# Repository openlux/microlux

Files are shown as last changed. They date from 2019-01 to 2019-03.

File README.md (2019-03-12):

This project is still in development.

# microlux

microlux is an open source design for an astrophotography autoguiding camera designed around the Aptina AR0130 image sensor.

### Hardware specifications

* AR0130 image sensor in ILCC48 package
  * 1280x960 resolution
  * 1/3-inch (6mm) diagonal size
  * 3.75um pixels
  * 78% peak quantum efficiency

* CY7C68013A microcontroller in QFN56 package
  * High speed USB 2.0 (480Mb/s)
  * Quad buffered 16/8 bit FIFO

* 40mm circular PCB
  * Designed to fit inside T2 / 42mm dust cap
  * 4x mounting holes for M2.5 screws (20mm square spacing)
  * Micro USB connector
  * RJ12 connector for ST4-compatible autoguiding

### PCB fab requirements

* Min. trace width 6mil
* Min. trace/pad spacing 6mil
* Min. drill 0.35mm
* Max. drill 2.7mm
* Min. via diameter 0.6mm
* Copper thickness 1.37mil (1oz/ft<sup>2</sup>)
* PCB thickness 0.8-1.6mm

### PCB photo

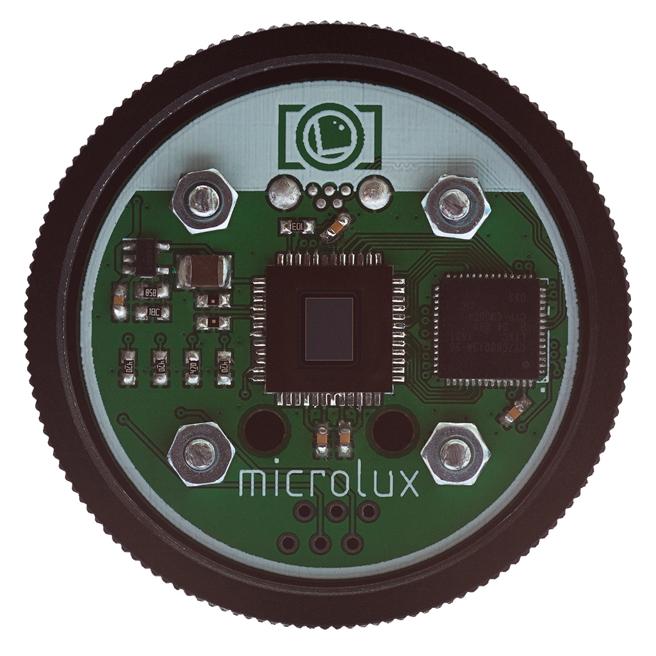
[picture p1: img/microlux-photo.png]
Microlux photo


### PCB render

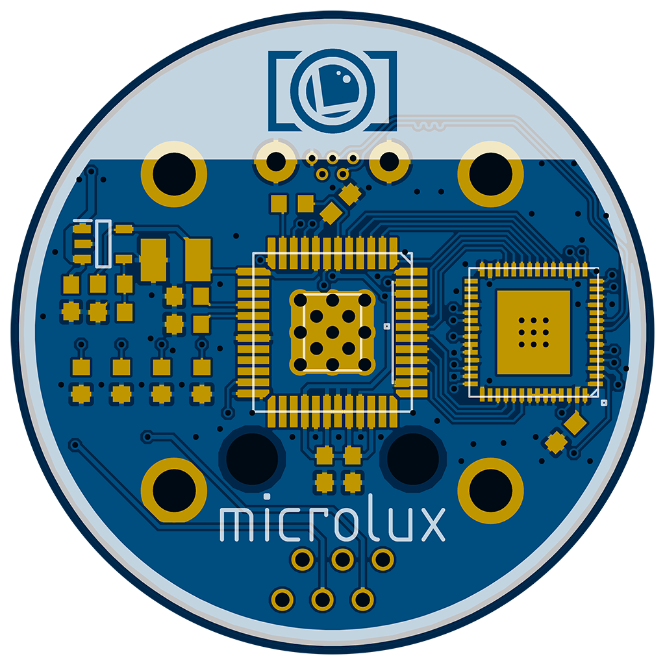
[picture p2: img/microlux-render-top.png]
Microlux PCB render


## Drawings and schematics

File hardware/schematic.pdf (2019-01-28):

A

A

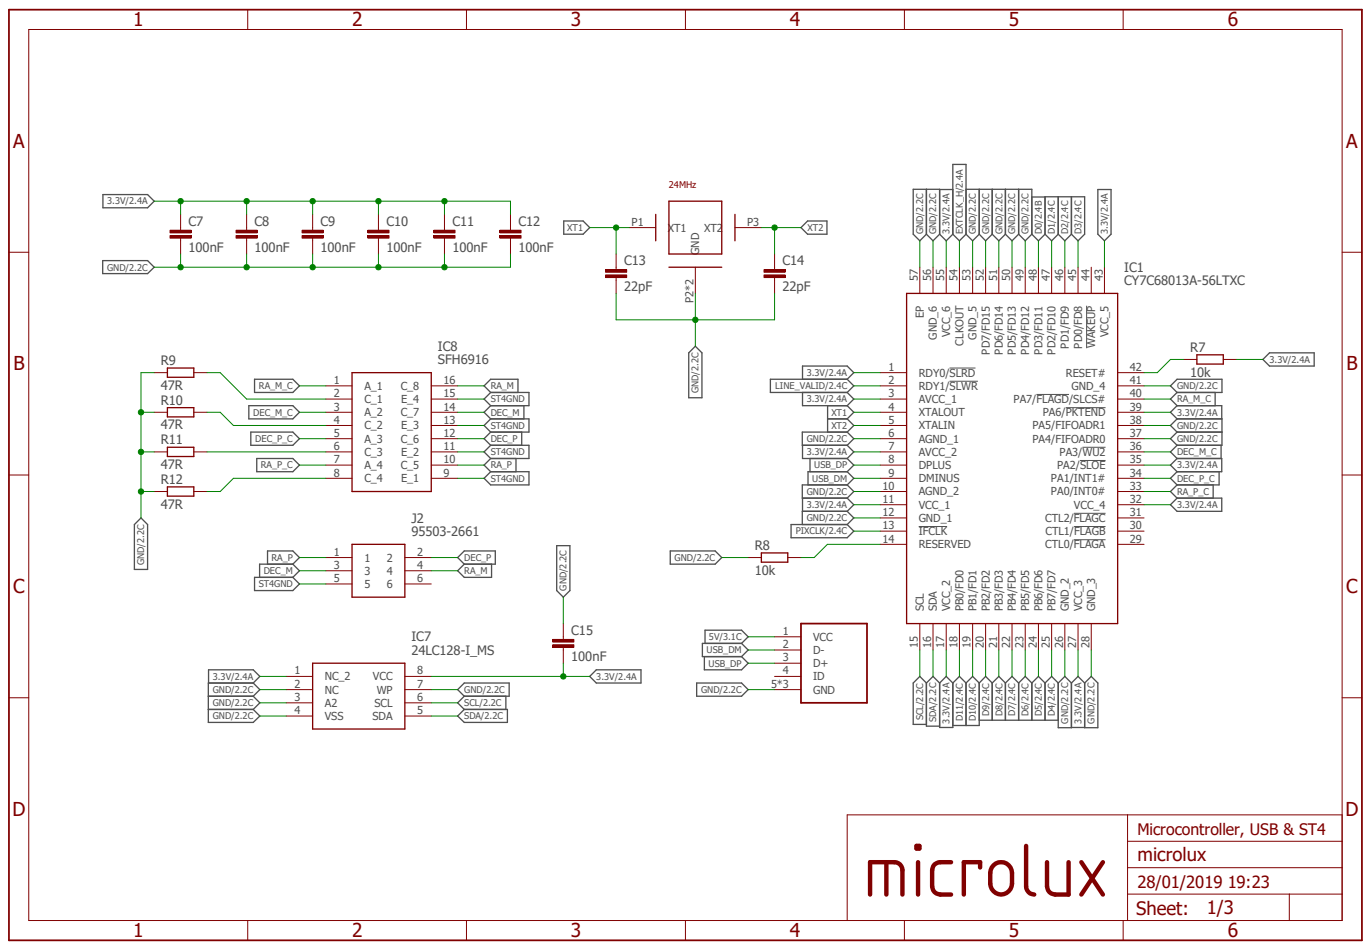
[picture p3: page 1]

## SN74LVC1T45DBVT

IC6

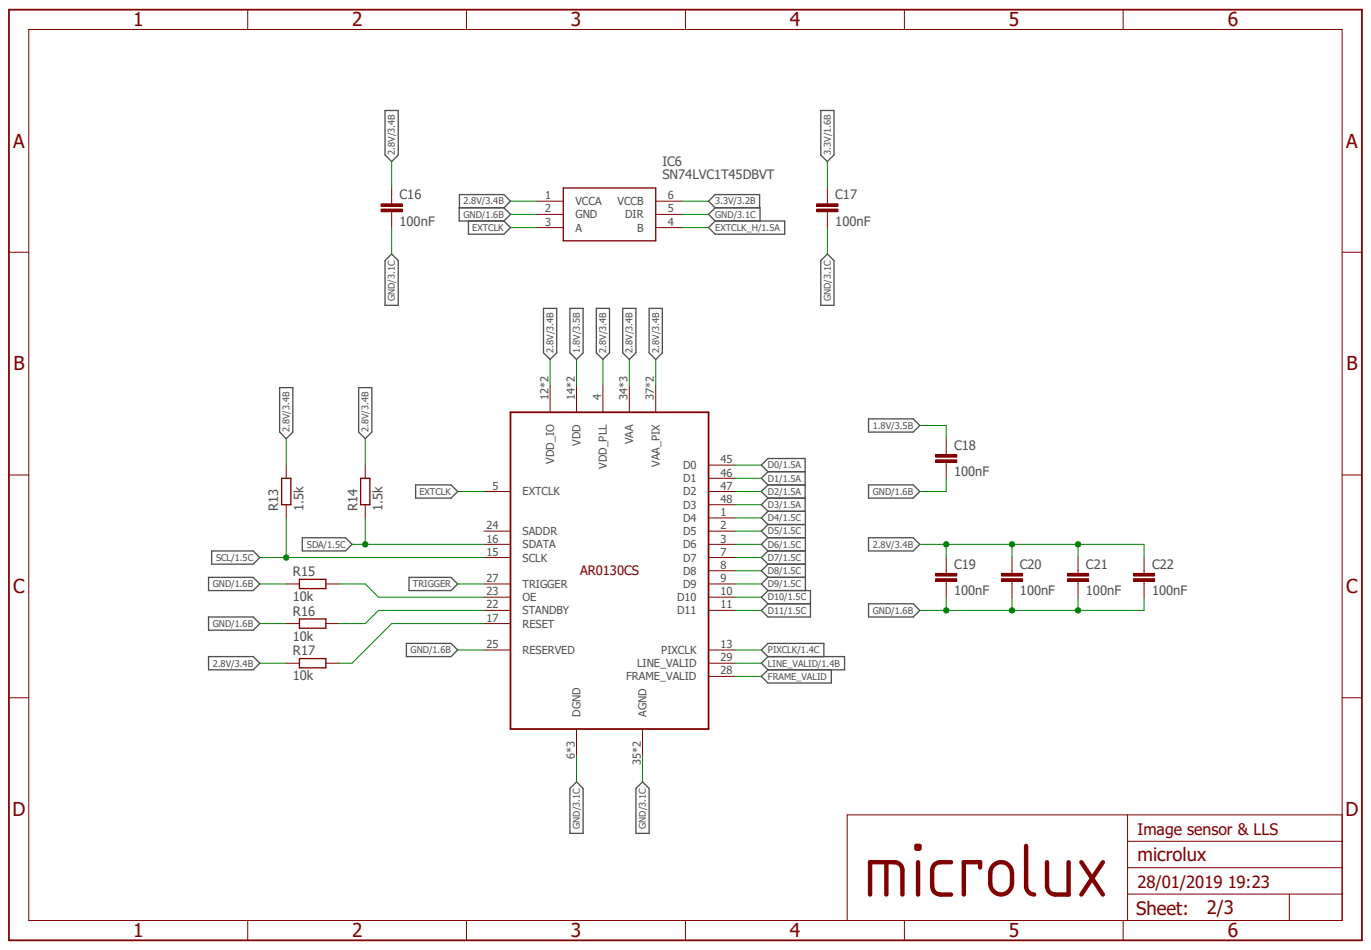
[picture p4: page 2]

A

A

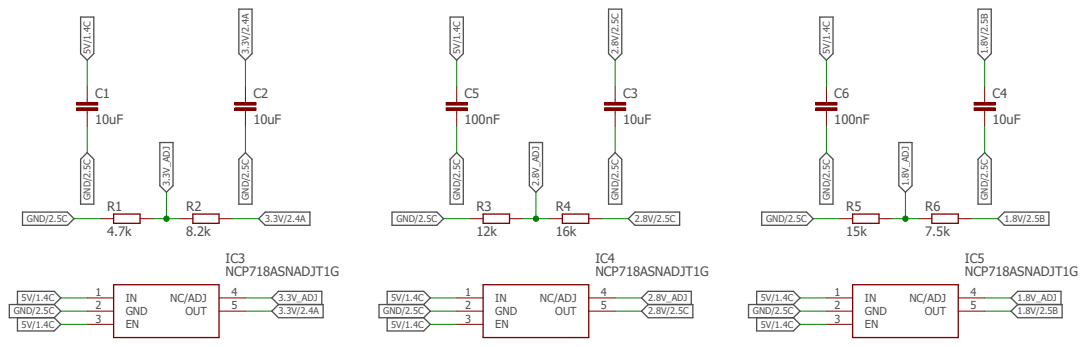
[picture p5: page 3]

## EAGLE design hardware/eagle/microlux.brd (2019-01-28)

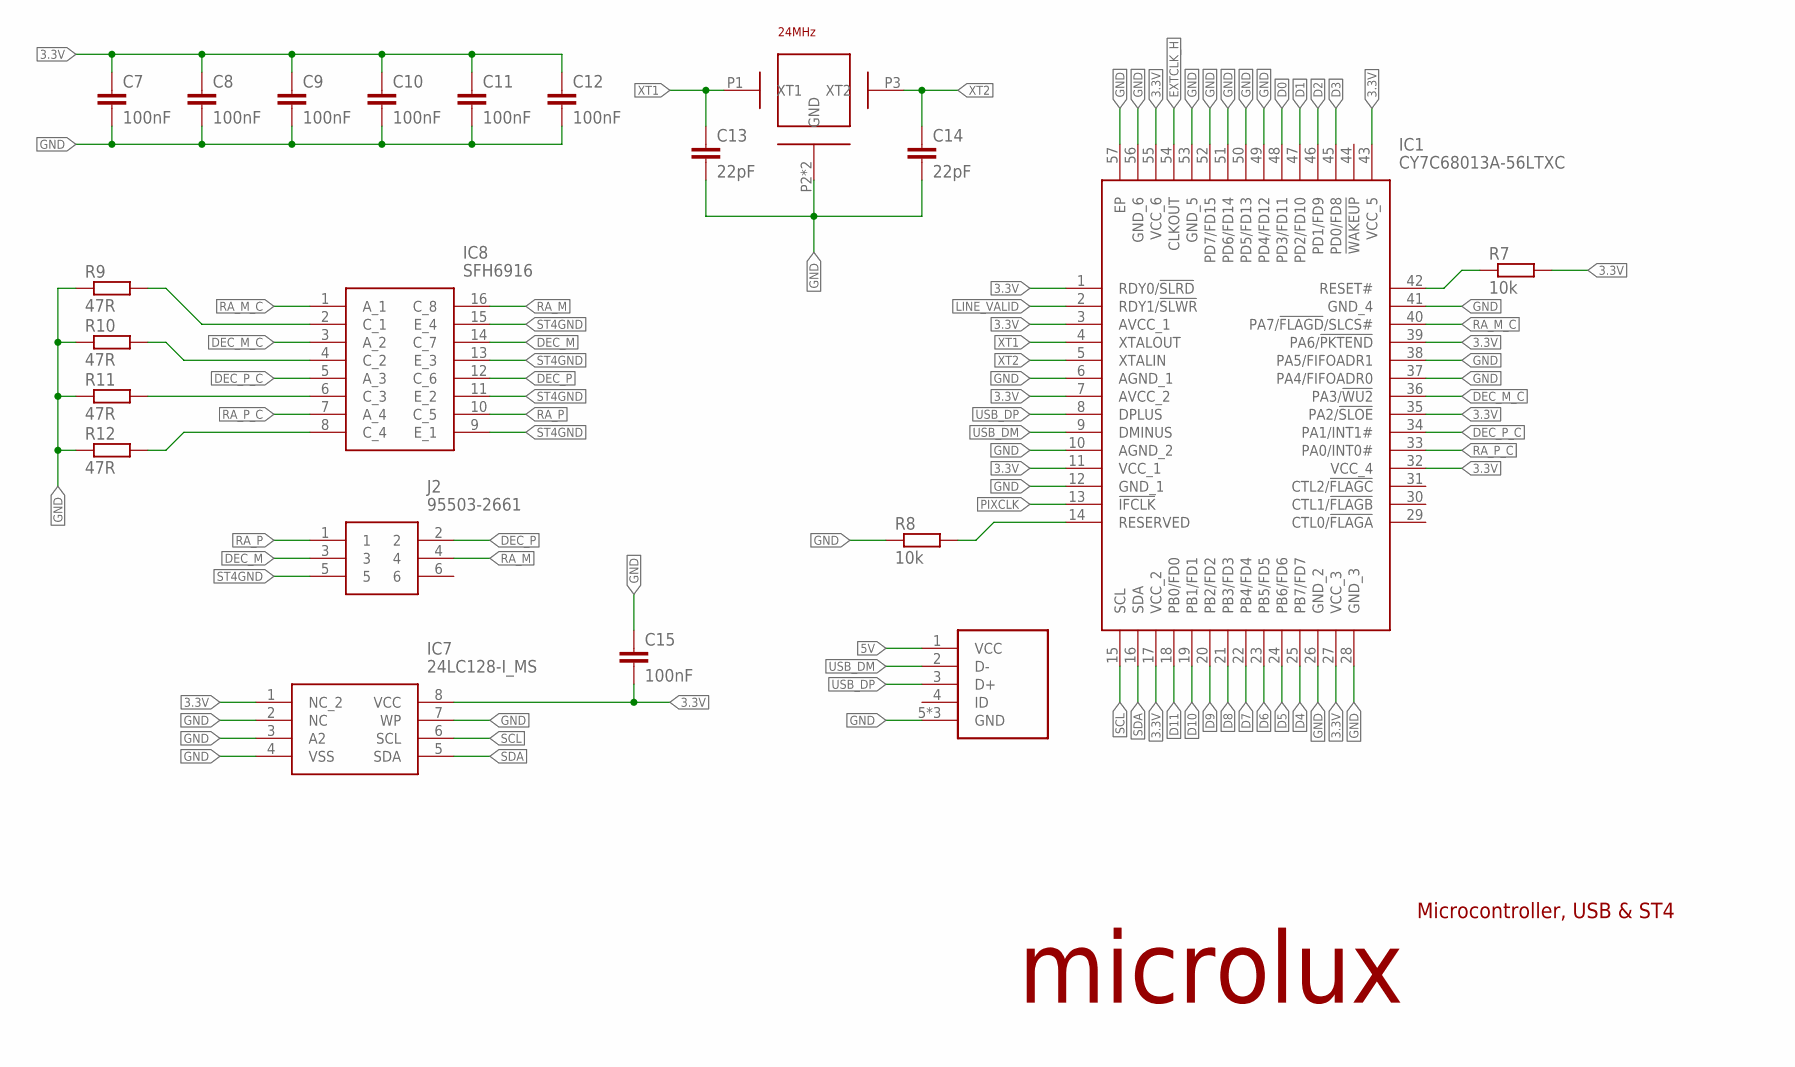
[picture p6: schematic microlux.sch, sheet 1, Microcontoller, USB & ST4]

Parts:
C7, C8, C9, C10, C11, C12, C15: 100nF; C0603
C13, C14: 22pF; C0603
IC1: CY7C68013A-56LTXC; QFN50P800X800X100-57N
IC7: 24LC128-I_MS; SOP65P490X110-8N
IC8: SFH6916; SOIC127P686X216-16N
J1: 614105150621; VMUSB
J2: 95503-2661; 955032661
R7, R8: 10k; R0603
R9, R10, R11, R12: 47R; R0603
X1: 24MHz; 3.2X2.5

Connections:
3.3V: C7.1, C8.1, C9.1, C10.1, C11.1, C12.1, C15.2, IC1.1 (RDY0/!SLRD), IC1.3 (AVCC_1), IC1.7 (AVCC_2), IC1.11 (VCC_1), IC1.17 (VCC_2), IC1.27 (VCC_3), IC1.32 (VCC_4), IC1.35 (PA2/!SLOE), IC1.39 (PA6/!PKTEND), IC1.43 (VCC_5), IC1.55 (VCC_6), IC7.1 (NC_2), IC7.8 (VCC), R7.2; also elsewhere on the board
5V: J1.1 (VCC); also elsewhere on the board
D0: IC1.48 (PD3/FD11); also elsewhere on the board
D1: IC1.47 (PD2/FD10); also elsewhere on the board
D2: IC1.46 (PD1/FD9); also elsewhere on the board
D3: IC1.45 (PD0/FD8); also elsewhere on the board
D4: IC1.25 (PB7/FD7); also elsewhere on the board
D5: IC1.24 (PB6/FD6); also elsewhere on the board
D6: IC1.23 (PB5/FD5); also elsewhere on the board
D7: IC1.22 (PB4/FD4); also elsewhere on the board
D8: IC1.21 (PB3/FD3); also elsewhere on the board
D9: IC1.20 (PB2/FD2); also elsewhere on the board
D10: IC1.19 (PB1/FD1); also elsewhere on the board
D11: IC1.18 (PB0/FD0); also elsewhere on the board
DEC_M: IC8.14 (C_7), J2.3
DEC_M_C: IC1.36 (PA3/!WU2), IC8.3 (A_2)
DEC_P: IC8.12 (C_6), J2.2
DEC_P_C: IC1.34 (PA1/INT1#), IC8.5 (A_3)
EXTCLK_H: IC1.54 (CLKOUT); also elsewhere on the board
GND: C7.2, C8.2, C9.2, C10.2, C11.2, C12.2, C13.2, C14.2, C15.1, IC1.6 (AGND_1), IC1.10 (AGND_2), IC1.12 (GND_1), IC1.26 (GND_2), IC1.28 (GND_3), IC1.37 (PA4/FIFOADR0), IC1.38 (PA5/FIFOADR1), IC1.41 (GND_4), IC1.49 (PD4/FD12), IC1.50 (PD5/FD13), IC1.51 (PD6/FD14), IC1.52 (PD7/FD15), IC1.53 (GND_5), IC1.56 (GND_6), IC1.57 (EP), IC7.2 (NC), IC7.3 (A2), IC7.4 (VSS), IC7.7 (WP), J1.5 (GND), J1.M1 (GND), J1.M2 (GND), R8.1, R9.1, R10.1, R11.1, R12.1, X1.P2 (GND), X1.P4 (GND); also elsewhere on the board
LINE_VALID: IC1.2 (RDY1/!SLWR); also elsewhere on the board
unnamed: IC1.14 (RESERVED), R8.2
unnamed: IC8.2 (C_1), R9.2
unnamed: IC1.42 (RESET#), R7.1
unnamed: IC8.4 (C_2), R10.2
unnamed: IC8.6 (C_3), R11.2
unnamed: IC8.8 (C_4), R12.2
PIXCLK: IC1.13 (!IFCLK); also elsewhere on the board
RA_M: IC8.16 (C_8), J2.4
RA_M_C: IC1.40 (PA7/!FLAGD!/SLCS#), IC8.1 (A_1)
RA_P: IC8.10 (C_5), J2.1
RA_P_C: IC1.33 (PA0/INT0#), IC8.7 (A_4)
SCL: IC1.15 (SCL), IC7.6 (SCL); also elsewhere on the board
SDA: IC1.16 (SDA), IC7.5 (SDA); also elsewhere on the board
ST4GND: IC8.9 (E_1), IC8.11 (E_2), IC8.13 (E_3), IC8.15 (E_4), J2.5
USB_DM: IC1.9 (DMINUS), J1.2 (D-)
USB_DP: IC1.8 (DPLUS), J1.3 (D+)
XT1: C13.1, IC1.4 (XTALOUT), X1.P1 (XT1)
XT2: C14.1, IC1.5 (XTALIN), X1.P3 (XT2)

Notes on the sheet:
microlux
Microcontroller, USB & ST4

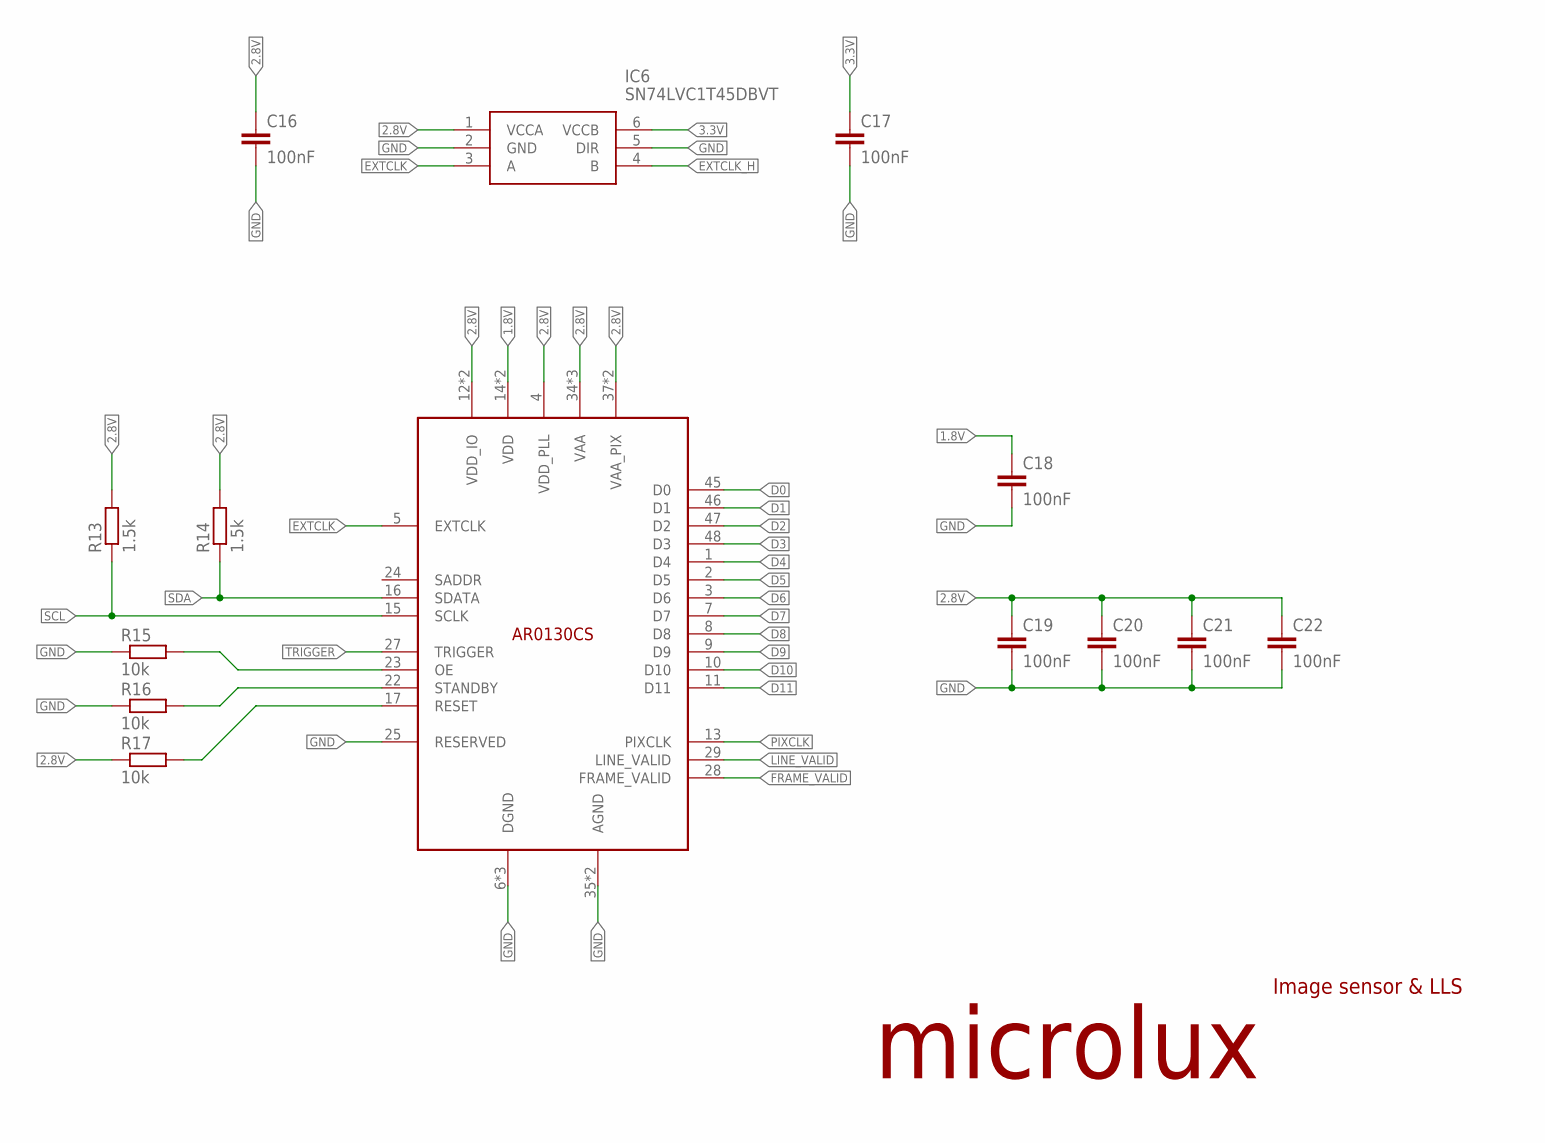
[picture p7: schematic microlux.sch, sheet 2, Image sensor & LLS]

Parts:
C16, C17, C18, C19, C20, C21, C22: 100nF; C0603
IC2: AR0130CS-ILCC48; ILCC48
IC6: SN74LVC1T45DBVT; SOT95P280X145-6N
R13, R14: 1.5k; R0603
R15, R16, R17: 10k; R0603

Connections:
1.8V: C18.1, IC2.14 (VDD), IC2.19 (VDD); also elsewhere on the board
2.8V: C16.1, C19.1, C20.1, C21.1, C22.1, IC2.4 (VDD_PLL), IC2.12 (VDD_IO), IC2.18 (VDD_IO), IC2.34 (VAA), IC2.36 (VAA), IC2.37 (VAA_PIX), IC2.38 (VAA_PIX), IC2.40 (VAA), IC6.1 (VCCA), R13.2, R14.2, R17.1; also elsewhere on the board
3.3V: C17.1, IC6.6 (VCCB); also elsewhere on the board
D0: IC2.45 (D0); also elsewhere on the board
D1: IC2.46 (D1); also elsewhere on the board
D2: IC2.47 (D2); also elsewhere on the board
D3: IC2.48 (D3); also elsewhere on the board
D4: IC2.1 (D4); also elsewhere on the board
D5: IC2.2 (D5); also elsewhere on the board
D6: IC2.3 (D6); also elsewhere on the board
D7: IC2.7 (D7); also elsewhere on the board
D8: IC2.8 (D8); also elsewhere on the board
D9: IC2.9 (D9); also elsewhere on the board
D10: IC2.10 (D10); also elsewhere on the board
D11: IC2.11 (D11); also elsewhere on the board
EXTCLK: IC2.5 (EXTCLK), IC6.3 (A)
EXTCLK_H: IC6.4 (B); also elsewhere on the board
FRAME_VALID: IC2.28 (FRAME_VALID)
GND: C16.2, C17.2, C18.2, C19.2, C20.2, C21.2, C22.2, IC2.6 (DGND), IC2.25 (RESERVED), IC2.30 (DGND), IC2.35 (AGND), IC2.39 (AGND), IC2.44 (DGND), IC6.2 (GND), IC6.5 (DIR), R15.1, R16.1; also elsewhere on the board
LINE_VALID: IC2.29 (LINE_VALID); also elsewhere on the board
unnamed: IC2.23 (OE), R15.2
unnamed: IC2.22 (STANDBY), R16.2
unnamed: IC2.17 (RESET), R17.2
PIXCLK: IC2.13 (PIXCLK); also elsewhere on the board
SCL: IC2.15 (SCLK), R13.1; also elsewhere on the board
SDA: IC2.16 (SDATA), R14.1; also elsewhere on the board
TRIGGER: IC2.27 (TRIGGER)

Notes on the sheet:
microlux
Image sensor & LLS

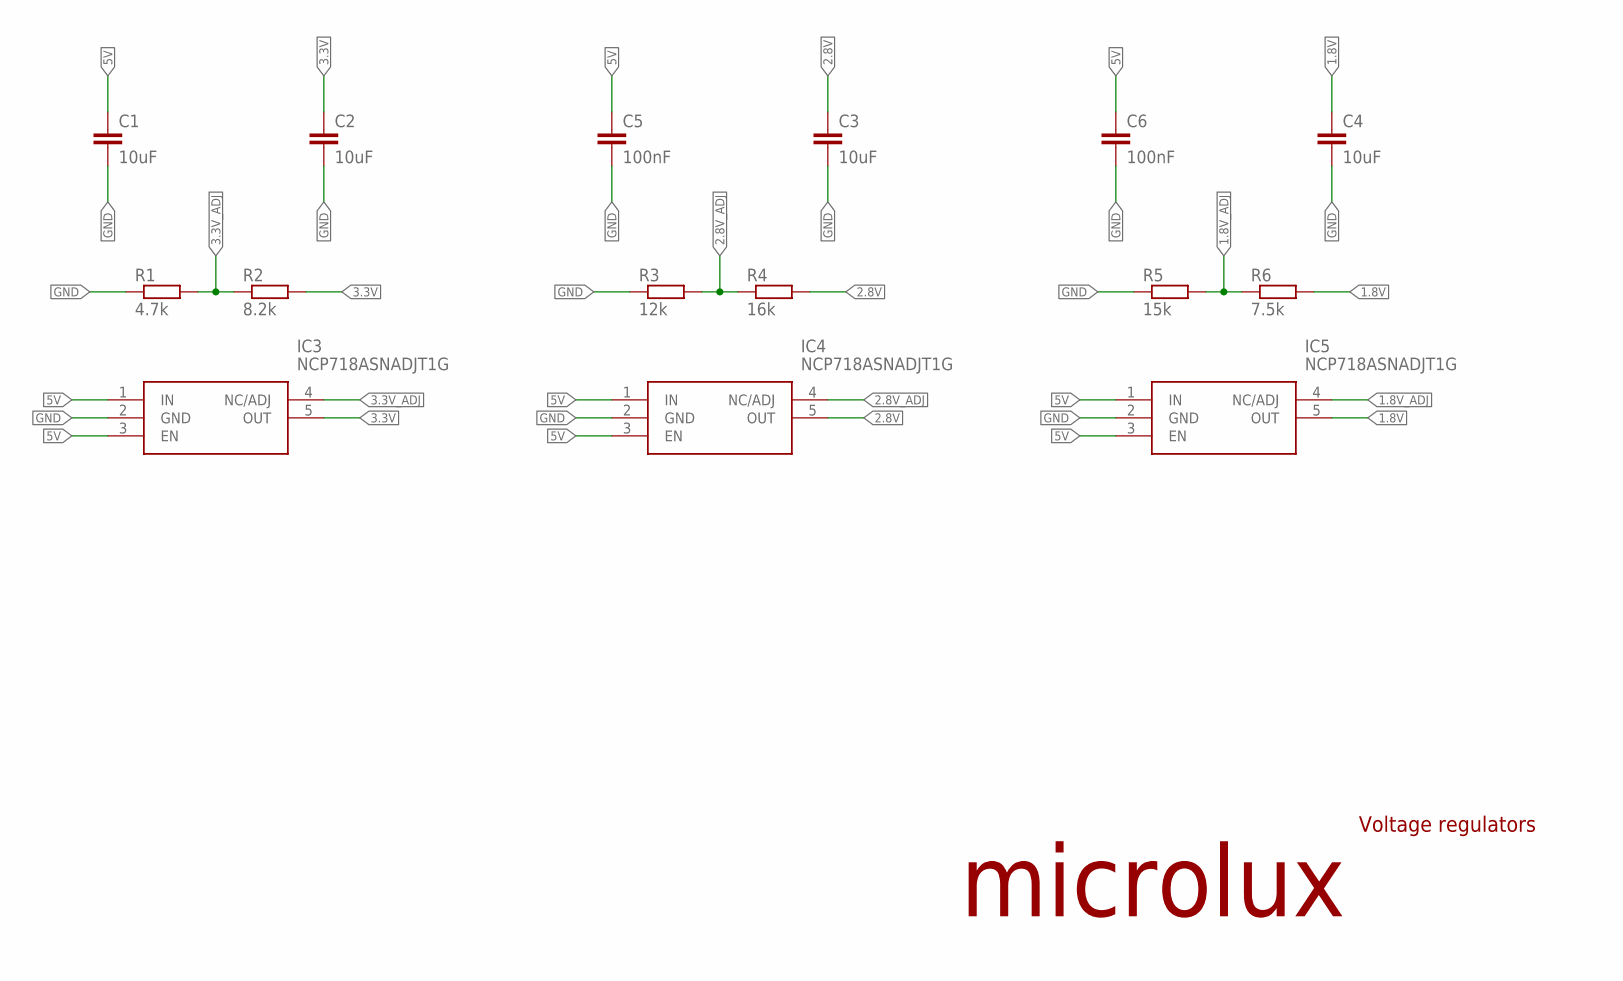
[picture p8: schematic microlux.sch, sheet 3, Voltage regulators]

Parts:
C1, C2, C3, C4: 10uF; C1210
C5, C6: 100nF; C0603
IC3, IC4, IC5: NCP718ASNADJT1G; SOT95P280X100-5N
R1: 4.7k; R0603
R2: 8.2k; R0603
R3: 12k; R0603
R4: 16k; R0603
R5: 15k; R0603
R6: 7.5k; R0603

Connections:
1.8V: C4.1, IC5.5 (OUT), R6.2; also elsewhere on the board
1.8V_ADJ: IC5.4 (NC/ADJ), R5.2, R6.1
2.8V: C3.1, IC4.5 (OUT), R4.2; also elsewhere on the board
2.8V_ADJ: IC4.4 (NC/ADJ), R3.2, R4.1
3.3V: C2.1, IC3.5 (OUT), R2.2; also elsewhere on the board
3.3V_ADJ: IC3.4 (NC/ADJ), R1.2, R2.1
5V: C1.1, C5.1, C6.1, IC3.1 (IN), IC3.3 (EN), IC4.1 (IN), IC4.3 (EN), IC5.1 (IN), IC5.3 (EN); also elsewhere on the board
GND: C1.2, C2.2, C3.2, C4.2, C5.2, C6.2, IC3.2 (GND), IC4.2 (GND), IC5.2 (GND), R1.1, R3.1, R5.1; also elsewhere on the board

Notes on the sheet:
microlux
Voltage regulators

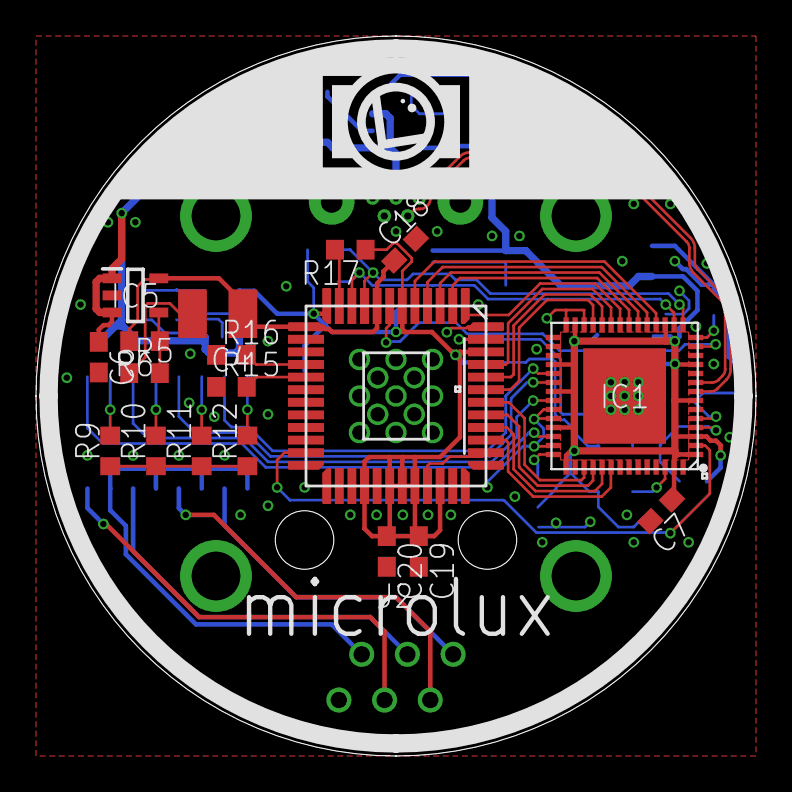
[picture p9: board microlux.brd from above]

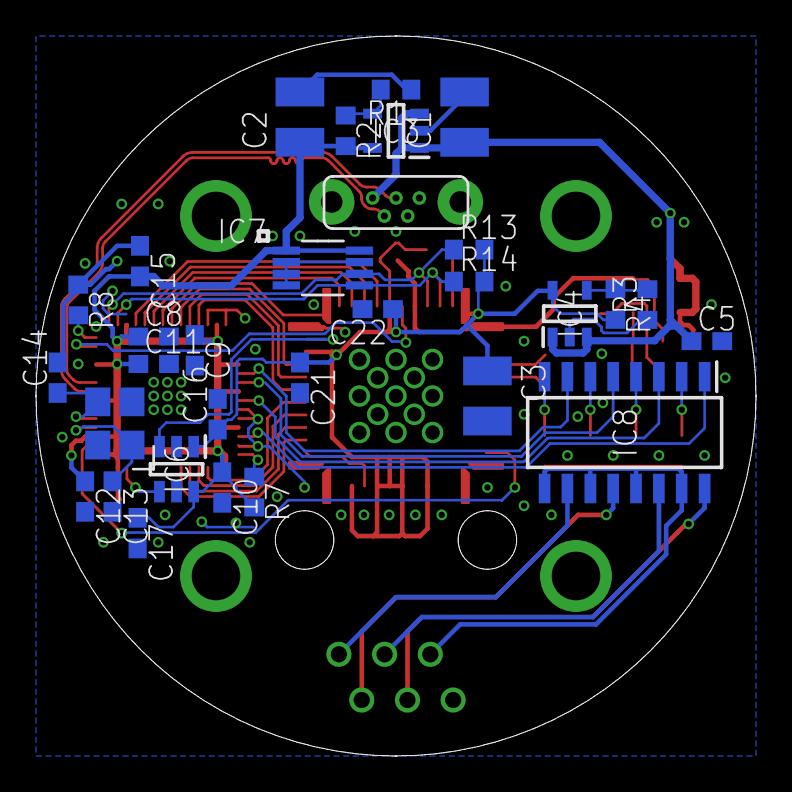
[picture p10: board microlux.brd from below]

Board: 2 copper layers, 40.0 x 40.0 mm, 50 parts (31 on the bottom side), 48 nets.

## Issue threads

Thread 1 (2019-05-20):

Status update

semenmiroshnichenko, 2019-05-20:
Hi there,

your project looks kind of interesting, what is the current state of this? Did you already build some camera samples, does it works at all?

jonathanedgecombe, 2019-05-21:
The current version of the hardware and software is able to take images (I've built one working sample of the hardware). However the code for driving the guide port has not been written yet and the corresponding parts of the hardware are untested. I'm hoping to make some additional changes to the PCB layout to fix a few small issues and then finish off the code in the next month or two.

semenmiroshnichenko, 2019-05-22:
Thanks @jonathanedgecombe. I would either think about using CY7C68013A interfacing with MT9M001 (used in old QHY5 cameras) sensor and your firmware as reference because I already have this sensor and would like to play with it. There is other Ukrainian project CAM10 I already build (http://astroccd.org/2014/12/cam10-desc), but using Cypress controller is more convenient IMHO (cheaper, has 16 bit parallel bus, no need for additional chips like in CAM10).
Could you link some images taken with your camera?

jonathanedgecombe, 2019-05-24:
Only sample image I have to hand is this one, https://i.imgur.com/G0YIMnch.jpg

Aprox. 5 hrs total exposure time (5 min subs) w/ 335mm f/5.2 scope using LRGB filters.

I could post some fits files of individual exposures and dark frames in a few days (currently away from home) if you're interested.

semenmiroshnichenko, 2019-05-25:
Imgur gets 404 error. And yes, I'm interested!

jonathanedgecombe, 2019-05-27:
Whoops, sorry, fixed the link now.

I've also uploaded some samples of fits files at http://jonathanedgecombe.com/microlux-samples/

Those were all taken with the same 335mm focal length f/5.2 scope. The brightest stars in the 4s and 8s samples are around magnitudes 9 to 11.

jiangred, 2022-07-24:
> The current version of the hardware and software is able to take images (I've built one working sample of the hardware). However the code for driving the guide port has not been written yet and the corresponding parts of the hardware are untested. I'm hoping to make some additional changes to the PCB layout to fix a few small issues and then finish off the code in the next month or two.

A good project!
I have some issue with the I2C when using separate AR0130 sensor board and a FX2 development board.
When I connect AR0130's I2C to FX2's I2C, the PC can't recognize FX2 device, seems FX2 can't read its 24L128,
also when I change the 24L128's I2C address, try to force the FX2 enter "No EEPROM mode", but failed.
When I disconnect AR0130's I2C wire then FX2 works normally. There is 2K pullup to 2.8V in the AR0130's SDA and SCK ,
in 24L128 side there is no pullup( I remove the pullup resisters in FX2 board).

is it necessary that use a I2C level shifter between AR0130 I2C and CY7C68013? As the CY7CUSB68013 also connects to 24L128 and it is 3.3v powered.

jiangred, 2022-07-28:
OK. thanks for your reply. I will check the circuit again. I mearued the sensor's SCL and SDA voltage,( pulled up to 2.8V) it is 1.8V, seems strange, maybe the sensor board has some problem. I will replace the senosr board and back about my result.

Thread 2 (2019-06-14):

How to upload firmware on the camera

semenmiroshnichenko, 2019-06-14:
I was able to build your firmware, but I am not really familiar with CY7C68013A, can you describe how can I upload the firmware on the CY7C68013 chip?

jonathanedgecombe, 2019-06-14:
If you're using windows then you can use the CyControl application included in the devkit software to upload the firmware, there's a download link to that on this page https://www.cypress.com/documentation/development-kitsboards/cy3684-ez-usb-fx2lp-development-kit

You can use CyControl to upload the hex file straight to the chip's RAM, I'd recommend sticking to that while doing development. To upload it to the EEPROM you'll need to use the hex2bix utility, also included with the devkit, to convert it to the right file format for CyControl to upload.

If you're on linux then there is a utility called fx2load for uploading firmware, although I haven't used it myself.

grahamedgecombe, 2019-06-14:
> If you're on linux then there is a utility called fx2load for uploading firmware, although I haven't used it myself.

you can just use the `make load` target on Linux

semenmiroshnichenko, 2019-06-14:
Yup I am on linux. make load is almost did the trick, but it gives me "Device not opened." message.
When I type dmesg:
[ 2470.540149] usb 2-1.2: new high-speed USB device number 15 using ehci-pci
[ 2470.632372] usb 2-1.2: New USB device found, idVendor=04b4, idProduct=8613
[ 2470.632382] usb 2-1.2: New USB device strings: Mfr=0, Product=0, SerialNumber=0
[ 2470.633031] usbtest 2-1.2:1.0: FX2 device
[ 2470.633040] usbtest 2-1.2:1.0: high-speed {control bulk-in bulk-out} tests (+alt)

make load:
_objcopy -I ihex -O binary build/microlux.ihx build/microlux.bix
fx2load -v 0x04b4 -p 0x8613 build/microlux.bix
Device not opened.
Put device in reset
Device not opened.
Error: -1
loading bix file of length: 16312
Device not opened.
Error: -1
Set device to run
Device not opened.
Error: -1
Device not opened._

I'm using cheap EZ-USB FX2LP board from China.

semenmiroshnichenko, 2019-06-15:
Ok, I got the firmware loaded on my board, I need to unload the "usbtest" kernel module (same issue as described here https://sigrok.org/wiki/Lcsoft_Mini_Board in section "possible issues")
So if one get this "device not opened" problem just unload usbtest module with  _sudo rmmod usbtest_

Closed 2019-06-15.

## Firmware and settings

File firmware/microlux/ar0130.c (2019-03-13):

#include <stdbool.h>
#include <string.h>
#include <fx2macros.h>
#include <delay.h>

#include "ar0130.h"
#include "microlux.h"
#include "i2c.h"
#include "usb_fifo.h"

#define AR0130_ADDR 0x20

#define AR0130_REGISTER_RESET 0x301A
#define AR0130_RESET_DEFAULT  0x00C8

#define AR0130_STREAM 0x0004
#define AR0130_RESET  0x0001

#define AR0130_REGISTER_PLL 0x30B0
#define AR0130_PLL_DEFAULT  0x5C00

#define AR0130_REGISTER_DARK_CONTROL 0x3044
#define AR0130_DARK_CONTROL_DEFAULT 0x0080

#define AR0130_REGISTER_X_START 0x3004
#define AR0130_REGISTER_X_END   0x3008
#define AR0130_REGISTER_Y_START 0x3002
#define AR0130_REGISTER_Y_END   0x3006

#define AR0130_REGISTER_GAIN   0x305E
#define AR0130_REGISTER_OFFSET 0x301E

#define AR0130_REGISTER_EXPOSURE_DURATION 0x3012
#define AR0130_REGISTER_LINE_WIDTH        0x300C

struct ar0130_exposure_config exposure_config;

bool exposing = false;

static uint16_t ar0130_read(uint16_t reg) {
    uint8_t buf[] = {
        (uint8_t) (reg >> 8),
        (uint8_t) reg
    };
    struct i2c_msg msgs[] = {
        {
            .address = AR0130_ADDR,
            .buf = &buf,
            .len = sizeof(buf)
        },
        {
            .address = AR0130_ADDR | I2C_READ,
            .buf = &buf,
            .len = sizeof(buf)
        }
    };
    i2c_transfer(msgs, sizeof(msgs) / sizeof(msgs[0]));
    return (buf[0] << 8) | buf[1];
}

static void ar0130_write(uint16_t reg, uint16_t value) {
    uint8_t buf[] = {
        (uint8_t) (reg >> 8),
        (uint8_t) reg,
        (uint8_t) (value >> 8),
        (uint8_t) value
    };
    struct i2c_msg msgs[] = {
        {
            .address = AR0130_ADDR,
            .buf = &buf,
            .len = sizeof(buf)
        }
    };
    i2c_transfer(msgs, sizeof(msgs) / sizeof(msgs[0]));
}

void ar0130_init(void) {
    /* bypass the PLL */
    ar0130_write(AR0130_REGISTER_PLL, AR0130_PLL_DEFAULT);

    /* enable zebra lines */
    ar0130_write(AR0130_REGISTER_DARK_CONTROL, AR0130_DARK_CONTROL_DEFAULT);

    /* enable parallel interface and disable stby_eof */
    ar0130_write(AR0130_REGISTER_RESET, AR0130_RESET_DEFAULT);
}

void ar0130_start_exposure(struct ar0130_exposure_config *new_config) {
    /* using memcmp() is fine here as structs are packed by default in sdcc */
    bool reset = memcmp(&exposure_config, new_config, sizeof(exposure_config));

    /* if exposure duration is >250ms (2097 lines) then reset the sensor to abort current exposure */
    if (exposing && reset && (exposure_config.duration_coarse > 2097)) {
        ar0130_stop_exposure();
    }

    ar0130_write(AR0130_REGISTER_X_START, new_config->x_start);
    ar0130_write(AR0130_REGISTER_X_END,   new_config->x_end);
    ar0130_write(AR0130_REGISTER_Y_START, new_config->y_start);
    ar0130_write(AR0130_REGISTER_Y_END,   new_config->y_end);

    ar0130_write(AR0130_REGISTER_GAIN,    new_config->gain);
    ar0130_write(AR0130_REGISTER_OFFSET,  new_config->offset);

    ar0130_write(AR0130_REGISTER_EXPOSURE_DURATION, new_config->duration_coarse);
    ar0130_write(AR0130_REGISTER_LINE_WIDTH,        new_config->line_width);

    memcpy(&exposure_config, new_config, sizeof(exposure_config));

    if (!exposing) {
        /* bypass the PLL */
        ar0130_write(AR0130_REGISTER_PLL, AR0130_PLL_DEFAULT);

        /* enable zebra lines */
        ar0130_write(AR0130_REGISTER_DARK_CONTROL, AR0130_DARK_CONTROL_DEFAULT);

        /* enable parallel interface, disable stby_eof and enable streaming */
        ar0130_write(AR0130_REGISTER_RESET, AR0130_RESET_DEFAULT | AR0130_STREAM);

        /* switch to external IFCLK */
        IFCONFIG = 0;
	SYNCDELAY;

        /* ensure EP2 is configured */
        EP2CFG = bmVALID | bmDIR | bmTYPE1;
        SYNCDELAY;

        usb_fifo_init();
    }

    exposing = true;
}

void ar0130_stop_exposure(void) {
    /* switch to internal 48 MHz IFCLK */
    IFCONFIG = bmIFCLKSRC | bm3048MHZ;
    SYNCDELAY;

    /* TODO disabiling EP2 here seems to break something */
    //EP2CFG &= ~bmVALID;
    //SYNCDELAY;

    /* wait for IFCLK switch */
    delay(1);

    /* reset AR0130, this aborts current exposure and disables streaming */
    ar0130_write(AR0130_REGISTER_RESET, AR0130_RESET_DEFAULT | AR0130_RESET);

    /* wait for sensor to start up, TODO longer duration? */
    delay(1);

    exposing = false;
}

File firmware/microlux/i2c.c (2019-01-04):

#include <fx2macros.h>

#include "i2c.h"

void i2c_init(void) {
    I2CTL |= bm400KHZ;
}

void i2c_transfer(struct i2c_msg *msgs, size_t len) {
    struct i2c_msg *next_msg;
    size_t msg_len;

retry:
    next_msg = msgs;
    msg_len = len;

    I2CS |= bmSTART;

    while (msg_len--) {
        struct i2c_msg *msg = next_msg++;

        if (I2CS & bmBERR) {
            /* TODO: start timer */
        }

        I2DAT = msg->address;
        while (!(I2CS & bmDONE)); /* TODO: wait for timer */

        if (I2CS & bmBERR) {
            goto retry;
        } else if (!(I2CS & bmACK)) {
            break;
        }

        uint8_t *buf = msg->buf;
        size_t buf_len = msg->len;

        if (msg->address & I2C_READ) {
            if (buf_len == 1) {
                I2CS |= bmLASTRD;
            }
            (void) I2DAT;

            while (buf_len--) {
                while (!(I2CS & bmDONE));

                if (I2CS & bmBERR) {
                    goto retry;
                }

                if (buf_len == 1) {
                    I2CS |= bmLASTRD;
                } else if (buf_len == 0) {
                    if (msg_len) {
                        I2CS |= bmSTART;
                    } else {
                        I2CS |= bmSTOP;
                    }
                }
                *buf++ = I2DAT;
            }
        } else {
            while (buf_len--) {
                I2DAT = *buf++;
                while (!(I2CS & bmDONE));

                if (I2CS & bmBERR) {
                    goto retry;
                } else if (!(I2CS & bmACK)) {
                    break;
                }
            }

            if (msg_len) {
                I2CS |= bmSTART;
            } else {
                I2CS |= bmSTOP;
            }
        }
    }

    while (I2CS & bmSTOP);
}

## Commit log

2019-01-04 Change vendor and product ID
    If we use 04B4:8613 Linux selects the usbtest driver rather than
    cdc_acm, so it doesn't create a /dev/ttyACM0 device.
2019-01-04 Add initial I2C driver
2019-01-05 Add trigger pin support
2019-01-05 Add AR0130 initialization code
    This seems to be the bare minimum to get PIXCLK running at 48 MHz ready
    for switching IFCLK to the external clock.
2019-01-05 Switch to external IFCLK after starting the AR0130 PIXCLK
2019-01-06 Flush EP2 on FRAME_VALID falling edges
2019-01-28 Add hardware
    [microlux.brd, microlux.sch]
2019-01-28 Add schematic pdf
2019-01-28 Remove unused interrupt
2019-02-13 Add initial ASCOM driver
2019-02-13 Add gerber files to .gitignore
2019-02-13 Replace compare_config with memcmp
    [ar0130.c]
2019-02-13 Make start_exposure static
    It doesn't need to be exposed publicly.
    [ar0130.c]
2019-02-13 Move camera_handle_command below ar0130_init for consistency
2019-02-13 Disable zero-length packets
    At one point I was thinking about using them for frame synchronization,
    but this is now done by looking for the frame's synchronization marker.
2019-02-13 Decouple AR0130 driver from the USB code
2019-02-13 Use switch in usb_ar0130_handle_command
    This is consistent with usb_cdc_handle_command.
2019-02-13 Add stop exposure support and disable frame streaming by default
2019-03-12 Reword pcb fab reqs in readme
2019-03-13 Fix exposure threshold to use current duration not new duration
    [ar0130.c]
2019-03-13 Add zebra lines to readout and decrease buffer size to reduce frame latency
